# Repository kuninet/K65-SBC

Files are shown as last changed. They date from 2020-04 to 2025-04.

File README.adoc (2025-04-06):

= 6502CPU シングルボードコンピューター =

== 概要 ==
* 6502CPUを使用したシングルボードコンピューターです。

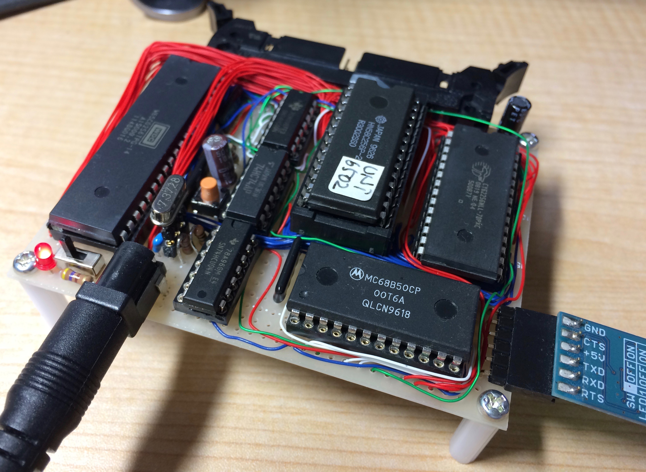
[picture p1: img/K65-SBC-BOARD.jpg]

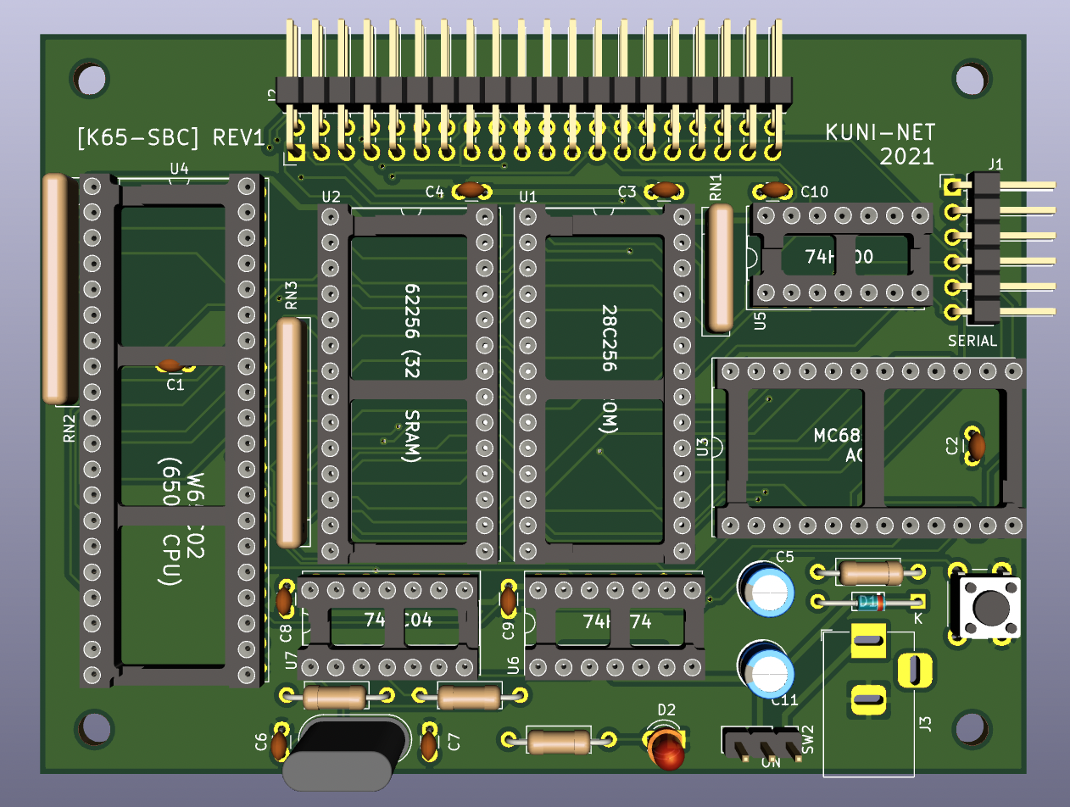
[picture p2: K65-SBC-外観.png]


== 特徴 ==
* Grantさんが公開している 6502コンピューターとアドレスを合わせてありますので、同じソフトが動きます。

== ディレクトリの説明 ==
* 回路図はimgディレクトリに入っています。
* KiCADデータはKiCadディレクトリです。
** 回路図の6502のシンボルは https://github.com/Alarm-Siren/6502-kicad-library[6502 KiCad Library]の成果を使用させていただきました。

* srcディレクトリにUniversal Monitor (Electrelicさん作)の移植用ソースを添付します。MC6850対応ドライバーを含んでいます。アセンブル済みのhexファイルも添付します。
** 28C256(256k)タイプのEEPROMへ、IntelHex形式のファイルから書き込んで使用してください。
** 書き込みの際、TL866CSを使う場合は、以下のように$Fxxxは$7xxxへ読み替える指定をしてください。

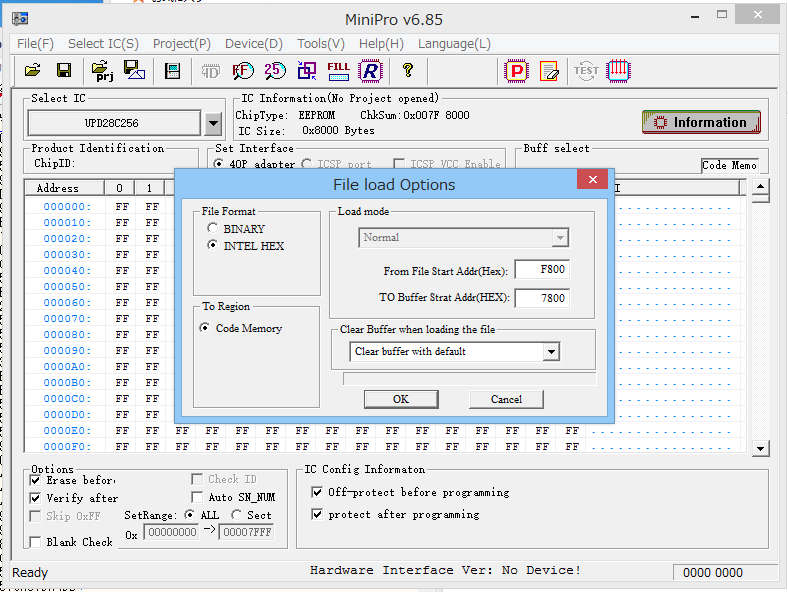
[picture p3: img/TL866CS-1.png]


== 参考 ==
* Grant's 8-chip (or 7-chip) 6502 computer
** http://searle.x10host.com/6502/Simple6502.html
* Universal Monitor (Electrelicさん)
** https://electrelic.com/electrelic/node/1318
* 6502 KiCad Library
** https://github.com/Alarm-Siren/6502-kicad-library

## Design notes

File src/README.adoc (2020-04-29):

= サンプルソース = 

== Universal Monitor MC6850(ACIA)対応

* ElectrelicさんのUniversal Monitor MC6850(ACIA)対応ソースサンプルとアセンブリ済みHEXファイルです。ROMに焼いてご使用ください。
* アセンブルするためにはThe Macroassembler ASの最新版が必要です。(Macro Assembler 1.42 Beta [Bld 162]でアセンブリ実績あり)

== SBC-IOのPIAを使ったLEDチカチカ (LED_BLINK)
* 6502マイコンとSBC-IOを接続して、PIA経由でLEDチカチカさせるプログラムです。
** SBC-IOの外部端子 PA0〜PA7へLEDを接続してお楽しみください。

== SBC-IOのPTMを使ったドレミ演奏 (MC6840-PLAY)
* 6502マイコンとSBC-IOを接続して、PTMでドレミ演奏するプログラムです。
** SBC-IOに圧電スピーカー等を接続してお楽しみください。

== URL
* Universal Monitor (Electrelicさん)
** https://electrelic.com/electrelic/node/1318
* The Macroassembler AS
** http://john.ccac.rwth-aachen.de:8000/as/
* SBC-IO REV2
** https://sbc738827564.wordpress.com/2018/08/11/sbc-io-rev02/

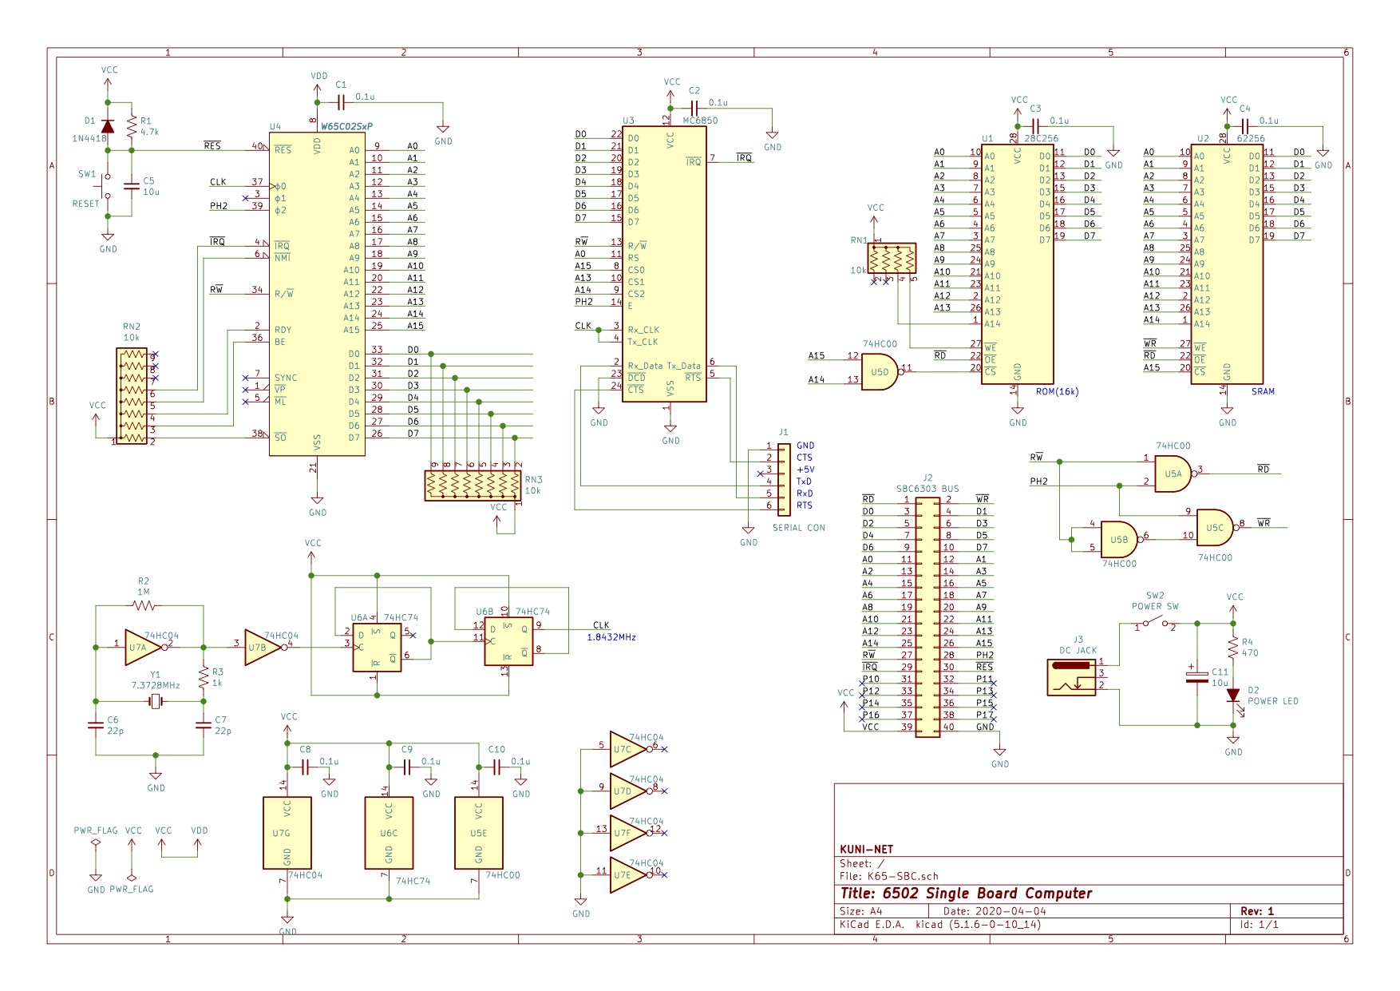
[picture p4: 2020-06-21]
img/K65-SBC.jpg

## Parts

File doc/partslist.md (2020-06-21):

# K65-SBC 部品表

|部品番号|仕様|数量|備考|
|:---:|:---|---:|:---|
|C1-C4,C8,C9,C10|0.1uF|7|積層セラミックコンデンサ|
|C5|10uF|1|電解コンデンサ|
|C6,C7|22pF|2|積層セラミックコンデンサ|
|C11|10uF|1|電解コンデンサ|
|D1|1N4418|1|小信号ダイオード|
|D2|3mm LED|1|POWER LED|
|J1|1x6L型型ピンヘッダ|1|SERIAL CON|
|J2|2x20(40ピン)L型ボックスヘッダ|1|SBC6303 BUS|
|J3||1|DC JACK|
|R1|4.7k|1|カーボーン抵抗器|
|R2|1M|1|カーボン抵抗器|
|R3|1k|1|カーボン抵抗器|
|R4|470|1|LED用カーボン抵抗|
|RN1|10k|1|4素子集合抵抗器|
|RN2,3|10k|2|8素子集合抵抗器|
|SW1|タクトスイッチ|1|RESET|
|SW2|基板用スライドSW|1|POWER SW|
|U1|28C256|1|フラッシュROM32kB|
|U2|62256|1|SRAM 32k|
|U3|MC6850|1|ACIAシリアルIC|
|U4|W65C02SxP|1|6502CPU|
|U5|74HC00|1|NANDゲート|
|U6|74HC74|1|D-FF|
|U7|74HC04|1|NOTゲート|
|Y1|7.3728MHz|1|水晶振動子|
||40ピンICソケット|1||
||28ピンICソケット|2||
||24ピンICソケット|1||
||14ピンICソケット|3||

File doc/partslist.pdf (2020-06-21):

partslist.md | 2020/6/21

1 / 2

# K65-SBC 部品表

部品番号 | 仕様 | 数量 | 備考
C1-C4,C8,C9,C10 0.1uF | 7 積層セラミックコンデンサ
C5 | 10uF | 1 電解コンデンサ
C6,C7 | 22pF | 2 積層セラミックコンデンサ
C11 | 10uF | 1 電解コンデンサ
D1 | 1N4418 | 1 ⼩信号ダイオード
D2 | 3mm LED | 1 POWER LED
J1 | 1x6L型型ピンヘッダ | 1 SERIAL CON
J2 | 2x20(40ピン)L型ボックスヘッダ | 1 SBC6303 BUS
J3 | 1 DC JACK
R1 | 4.7k | 1 カーボーン抵抗器
R2 | 1M | 1 カーボン抵抗器
R3 | 1k | 1 カーボン抵抗器
R4 | 470 | 1 LED⽤カーボン抵抗
RN1 | 10k | 1 4素⼦集合抵抗器
RN2,3 | 10k | 2 8素⼦集合抵抗器
SW1 | タクトスイッチ | 1 RESET
SW2 | 基板⽤スライドSW | 1 POWER SW
U1 | 28C256 | 1 フラッシュROM32kB
U2 | 62256 | 1 SRAM 32k
U3 | MC6850 | 1 ACIAシリアルIC
U4 | W65C02SxP | 1 6502CPU
U5 | 74HC00 | 1 NANDゲート
U6 | 74HC74 | 1 D-FF
U7 | 74HC04 | 1 NOTゲート
Y1 | 7.3728MHz | 1 ⽔晶振動⼦
| 40ピンICソケット | 1
| 28ピンICソケット | 2

partslist.md | 2020/6/21

2 / 2

部品番号 | 仕様 | 数量 | 備考
| 24ピンICソケット | 1
| 14ピンICソケット | 3

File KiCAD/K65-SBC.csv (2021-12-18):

Reference | Value | Footprint | Datasheet
C1 | 0.1u | Capacitor_THT:C_Disc_D3.0mm_W1.6mm_P2.50mm | ~
C11 | 10u | Capacitor_THT:CP_Radial_D5.0mm_P2.50mm | ~
C2 | 0.1u | Capacitor_THT:C_Disc_D3.0mm_W1.6mm_P2.50mm | ~
C3 | 0.1u | Capacitor_THT:C_Disc_D3.0mm_W1.6mm_P2.50mm | ~
C4 | 0.1u | Capacitor_THT:C_Disc_D3.0mm_W1.6mm_P2.50mm | ~
C5 | 10u | Capacitor_THT:CP_Radial_D5.0mm_P2.50mm | ~
C6 | 22p | Capacitor_THT:C_Disc_D3.0mm_W1.6mm_P2.50mm | ~
C7 | 22p | Capacitor_THT:C_Disc_D3.0mm_W1.6mm_P2.50mm | ~
C8 | 0.1u | Capacitor_THT:C_Disc_D3.0mm_W1.6mm_P2.50mm | ~
C9 | 0.1u | Capacitor_THT:C_Disc_D3.0mm_W1.6mm_P2.50mm | ~
C10 | 0.1u | Capacitor_THT:C_Disc_D3.0mm_W1.6mm_P2.50mm | ~
D1 | 1N4418 | Diode_THT:D_DO-34_SOD68_P10.16mm_Horizontal | ~
D2 | POWER LED | LED_THT:LED_D3.0mm | ~
H1 | MountingHole | MountingHole:MountingHole_3.2mm_M3 | ~
H2 | MountingHole | MountingHole:MountingHole_3.2mm_M3 | ~
H3 | MountingHole | MountingHole:MountingHole_3.2mm_M3 | ~
H4 | MountingHole | MountingHole:MountingHole_3.2mm_M3 | ~
J1 | SERIAL CON | Connector_PinHeader_2.54mm:PinHeader_1x06_P2.54mm_Horizontal | ~
J2 | SBC6303 BUS | Connector_PinHeader_2.54mm:PinHeader_2x20_P2.54mm_Horizontal | ~
J3 | DC JACK | Connector_BarrelJack:BarrelJack_Horizontal | ~
R1 | 4.7k | Resistor_THT:R_Axial_DIN0207_L6.3mm_D2.5mm_P10.16mm_Horizontal | ~
R2 | 1M | Resistor_THT:R_Axial_DIN0207_L6.3mm_D2.5mm_P10.16mm_Horizontal | ~
R3 | 1k | Resistor_THT:R_Axial_DIN0207_L6.3mm_D2.5mm_P10.16mm_Horizontal | ~
R4 | 470 | Resistor_THT:R_Axial_DIN0207_L6.3mm_D2.5mm_P10.16mm_Horizontal | ~
RN1 | 10k | Resistor_THT:R_Array_SIP5 | http://www.vishay.com/docs/31509/csc.pdf
RN2 | 10k | Resistor_THT:R_Array_SIP9 | http://www.vishay.com/docs/31509/csc.pdf
RN3 | 10k | Resistor_THT:R_Array_SIP9 | http://www.vishay.com/docs/31509/csc.pdf
SW1 | RESET | Button_Switch_THT:SW_PUSH_6mm | ~
SW2 | POWER SW | Connector_PinHeader_2.54mm:PinHeader_1x03_P2.54mm_Vertical | ~
U1 | 28C256 | Package_TO_SOT_THT:TO-92_Inline_Wide | http://ww1.microchip.com/downloads/en/DeviceDoc/doc0006.pdf
U2 | 62256 | Package_DIP:DIP-28_W15.24mm_Socket_LongPads | http://ww1.microchip.com/downloads/en/DeviceDoc/doc0006.pdf
U3 | MC6850 | Package_DIP:DIP-24_W15.24mm_Socket_LongPads | http://pdf.datasheetcatalog.com/datasheet/motorola/MC6850.pdf
U4 | W65C02SxP | Package_DIP:DIP-40_W15.24mm_Socket_LongPads | http://www.westerndesigncenter.com/wdc/documentation/w65c02s.pdf
U5 | 74HC00 | Package_DIP:DIP-14_W7.62mm_Socket_LongPads | http://www.ti.com/lit/gpn/sn74hc00
U6 | 74HC74 | Package_DIP:DIP-14_W7.62mm_Socket_LongPads | 74xx/74hc_hct74.pdf
U7 | 74HC04 | Package_DIP:DIP-14_W7.62mm_Socket_LongPads | https://assets.nexperia.com/documents/data-sheet/74HC_HCT04.pdf
Y1 | 7.3728MHz | Crystal:Crystal_HC50_Vertical | ~

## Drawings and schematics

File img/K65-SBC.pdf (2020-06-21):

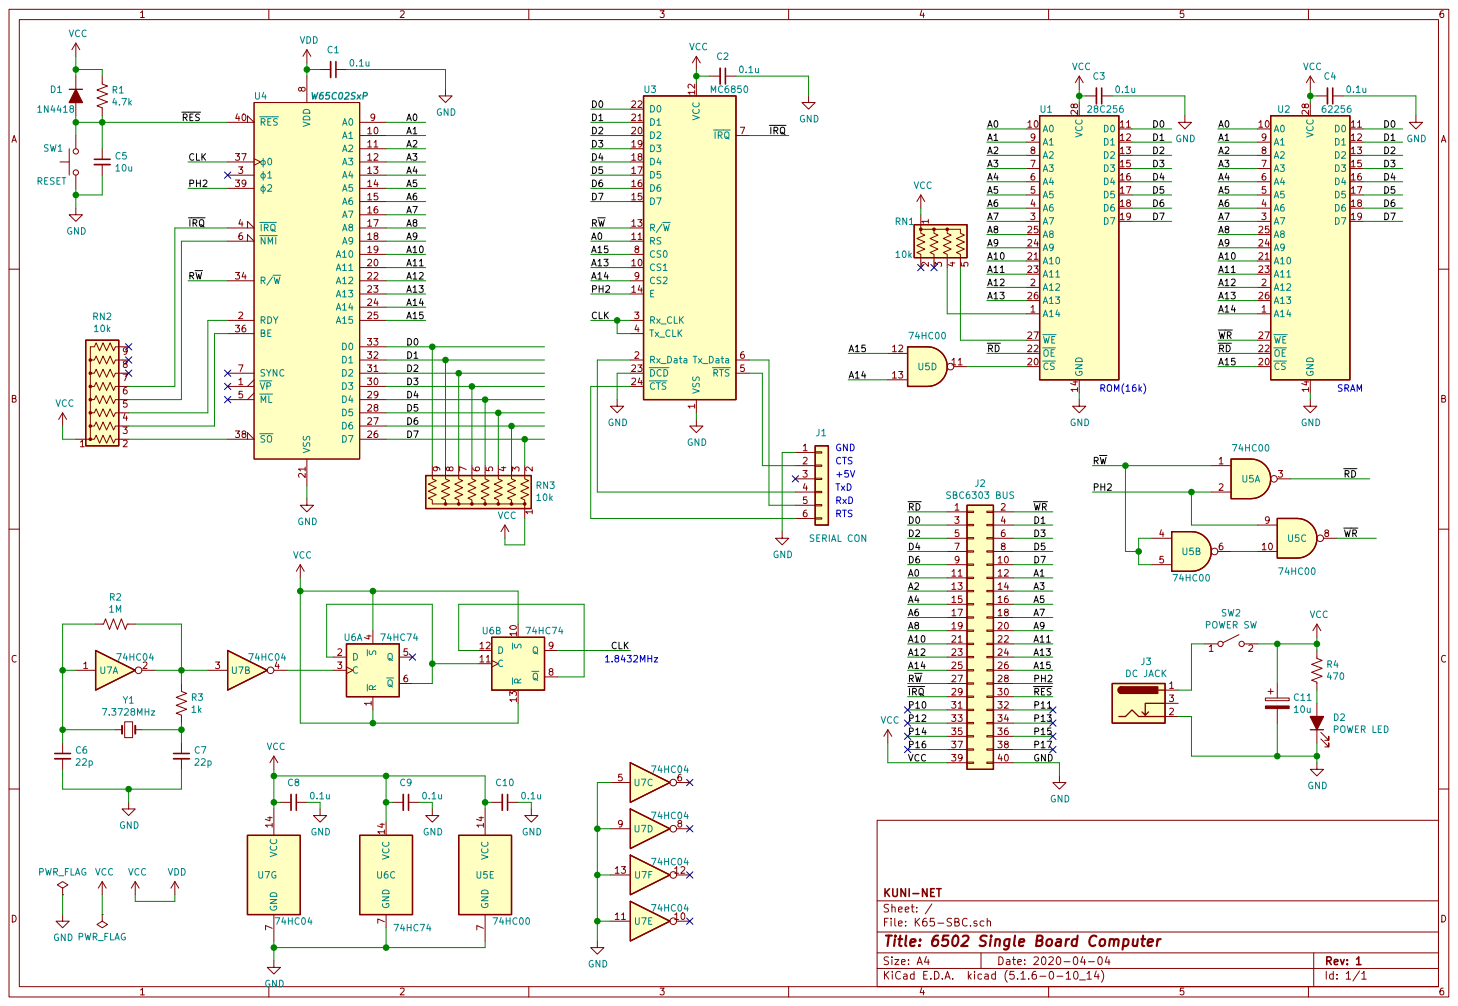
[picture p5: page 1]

Id: 1/1 Title: 6502 Single Board Computer File: K65-SBC.sch Sheet: / KUNI-NET R2

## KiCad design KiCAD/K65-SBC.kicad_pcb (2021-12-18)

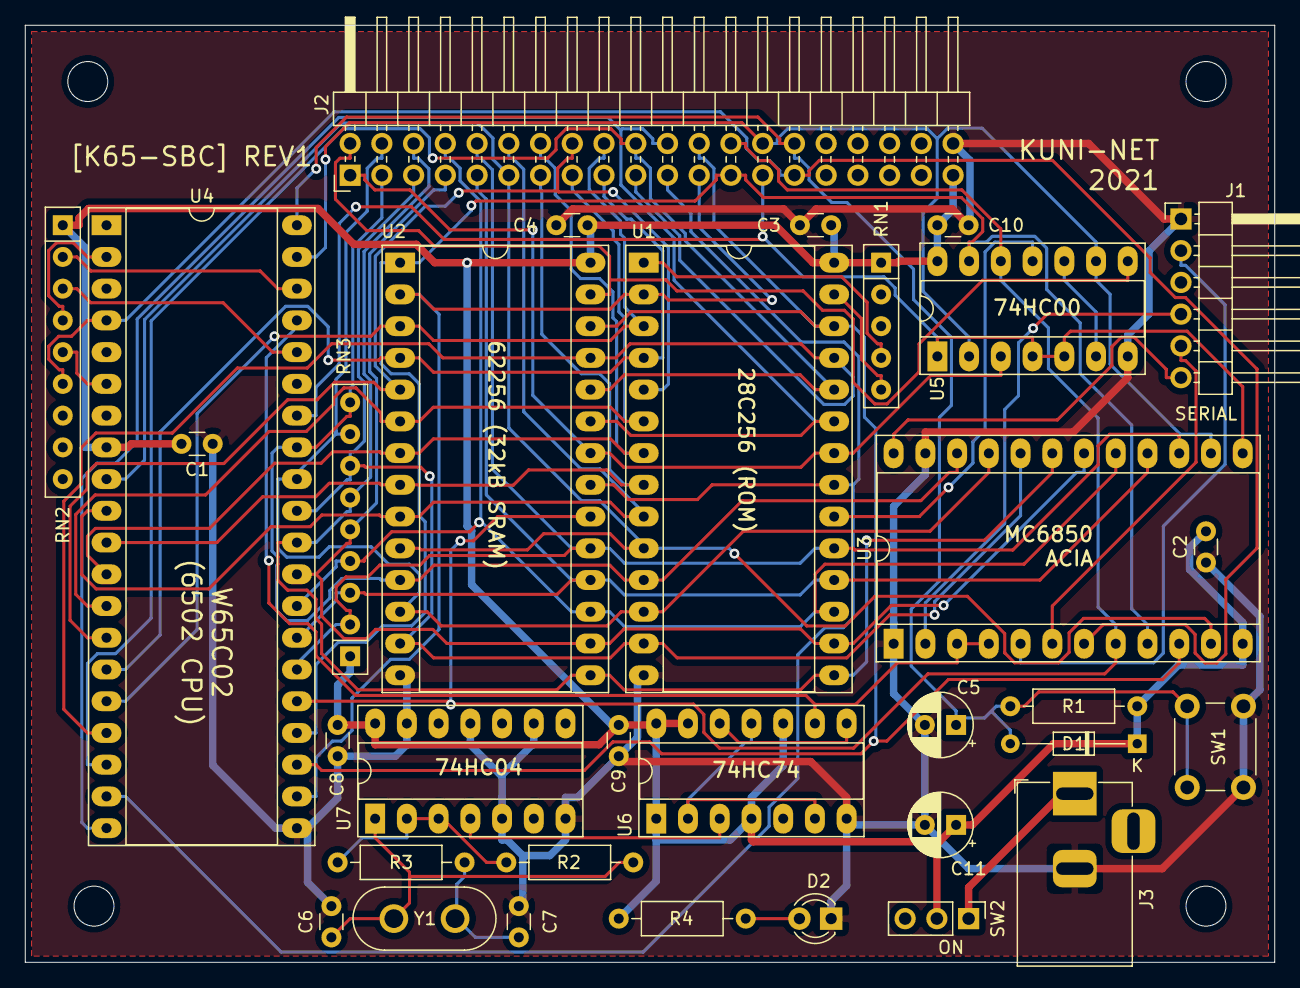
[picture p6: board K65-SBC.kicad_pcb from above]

Board: 2 copper layers, 100.0 x 75.0 mm, 37 parts (0 on the bottom side), 53 nets.

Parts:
C1, C2, C3, C4, C8, C9, C10: 0.1u; C_Disc_D3.0mm_W1.6mm_P2.50mm
C5, C11: 10u; CP_Radial_D5.0mm_P2.50mm
C6, C7: 22p; C_Disc_D3.0mm_W1.6mm_P2.50mm
D1: 1N4418; D_DO-34_SOD68_P10.16mm_Horizontal
D2: POWER LED; LED_D3.0mm
H1, H2, H3, H4: MountingHole; MountingHole_3.2mm_M3
J1: SERIAL CON; PinHeader_1x06_P2.54mm_Horizontal
J2: SBC6303 BUS; PinHeader_2x20_P2.54mm_Horizontal
J3: DC JACK; BarrelJack_Horizontal
R1: 4.7k; R_Axial_DIN0207_L6.3mm_D2.5mm_P10.16mm_Horizontal
R2: 1M; R_Axial_DIN0207_L6.3mm_D2.5mm_P10.16mm_Horizontal
R3: 1k; R_Axial_DIN0207_L6.3mm_D2.5mm_P10.16mm_Horizontal
R4: 470; R_Axial_DIN0207_L6.3mm_D2.5mm_P10.16mm_Horizontal
RN1: 10k; R_Array_SIP5
RN2, RN3: 10k; R_Array_SIP9
SW1: RESET; SW_PUSH_6mm
SW2: POWER SW; PinHeader_1x03_P2.54mm_Vertical
U1: 28C256; DIP-28_W15.24mm_Socket_LongPads
U2: 62256; DIP-28_W15.24mm_Socket_LongPads
U3: MC6850; DIP-24_W15.24mm_Socket_LongPads
U4: W65C02SxP; DIP-40_W15.24mm_Socket_LongPads
U5: 74HC00; DIP-14_W7.62mm_Socket_LongPads
U6: 74HC74; DIP-14_W7.62mm_Socket_LongPads
U7: 74HC04; DIP-14_W7.62mm_Socket_LongPads
Y1: 7.3728MHz; Crystal_HC50_Vertical

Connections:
/A0: J2.11, U1.10, U2.10, U3.11, U4.9
/A1: J2.12, U1.9, U2.9, U4.10
/A2: J2.13, U1.8, U2.8, U4.11
/A3: J2.14, U1.7, U2.7, U4.12
/A4: J2.15, U1.6, U2.6, U4.13
/A5: J2.16, U1.5, U2.5, U4.14
/A6: J2.17, U1.4, U2.4, U4.15
/A7: J2.18, U1.3, U2.3, U4.16
/A8: J2.19, U1.25, U2.25, U4.17
/A9: J2.20, U1.24, U2.24, U4.18
/A10: J2.21, U1.21, U2.21, U4.19
/A11: J2.22, U1.23, U2.23, U4.20
/A12: J2.23, U1.2, U2.2, U4.22
/A13: J2.24, U1.26, U2.26, U3.10, U4.23
/A14: J2.25, U2.1, U3.9, U4.24, U5.13
/A15: J2.26, U2.20, U3.8, U4.25, U5.12
/CLK: U3.3, U3.4, U4.37, U6.9
/D0: J2.3, RN3.9, U1.11, U2.11, U3.22, U4.33
/D1: J2.4, RN3.8, U1.12, U2.12, U3.21, U4.32
/D2: J2.5, RN3.7, U1.13, U2.13, U3.20, U4.31
/D3: J2.6, RN3.6, U1.15, U2.15, U3.19, U4.30
/D4: J2.7, RN3.5, U1.16, U2.16, U3.18, U4.29
/D5: J2.8, RN3.4, U1.17, U2.17, U3.17, U4.28
/D6: J2.9, RN3.3, U1.18, U2.18, U3.16, U4.27
/D7: J2.10, RN3.2, U1.19, U2.19, U3.15, U4.26
/PH2: J2.28, U3.14, U4.39, U5.2, U5.9
/R~W: J2.27, U3.13, U4.34, U5.1, U5.4, U5.5
/~IRQ: J2.29, RN2.6, U3.7, U4.4
/~RD: J2.1, U1.22, U2.22, U5.3
/~RES: C5.1, D1.2, J2.30, R1.2, SW1.2, U4.40
/~WR: J2.2, U2.27, U5.8
GND: C1.1, C2.1, C3.1, C4.1, C5.2, C6.2, C7.2, C8.1, C9.1, C10.1, C11.2, D2.1, J1.1, J2.40, J3.2, SW1.1, U1.14, U2.14, U3.1, U3.23, U4.21, U5.7, U6.7, U7.5, U7.7, U7.9, U7.11, U7.13
unnamed: C6.1, R2.2, U7.1, Y1.1
unnamed: C7.1, R3.2, Y1.2
unnamed: D2.2, R4.2
unnamed: J1.2, U3.5
unnamed: J1.4, U3.2
unnamed: J1.5, U3.6
unnamed: J1.6, U3.24
unnamed: J3.1, SW2.1
unnamed: R2.1, R3.1, U7.2, U7.3
unnamed: RN1.4, U1.1
unnamed: RN1.5, U1.27
unnamed: RN2.2, U4.38
unnamed: RN2.3, U4.36
unnamed: RN2.4, U4.2
unnamed: RN2.5, U4.6
unnamed: U1.20, U5.11
unnamed: U5.6, U5.10
unnamed: U6.3, U7.4
unnamed: U6.2, U6.6, U6.11
unnamed: U6.8, U6.12
VCC: C1.2, C2.2, C3.2, C4.2, C8.2, C9.2, C10.2, C11.1, D1.1, J2.39, R1.1, R4.1, RN1.1, RN2.1, RN3.1, SW2.2, U1.28, U2.28, U3.12, U4.8, U5.14, U6.1, U6.4, U6.10, U6.13, U6.14, U7.14

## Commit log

2020-04-10 各種ファイルコミット
    [K65-SBC.kicad_pcb, K65-SBC.sch]
2020-04-10 サンブル説明追加
2020-04-10 アセンブリ関係追記
2020-04-20 サンプルソース追加
2020-04-29 サンプロブログラム追加・修正
2020-06-21 回路図整備、部品表作成
    [K65-SBC.csv, K65-SBC.sch]
2020-06-21 回路図差し替え
2021-12-18 REV1ガーバーデータ出力
    [K65-SBC.GBL, K65-SBC.GBO, K65-SBC.GBP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]
